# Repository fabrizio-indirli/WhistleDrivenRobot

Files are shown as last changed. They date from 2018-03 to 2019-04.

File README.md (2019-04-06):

# Whistle Driven Robot

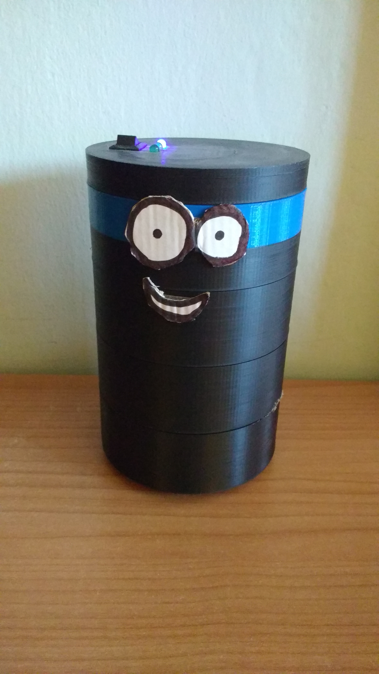
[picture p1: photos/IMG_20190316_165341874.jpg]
Robot Photo
 
This project was developed for the course _Advanced Operating
Systems_ in the academic year 2017/2018 on the Politecnico of Milan.

#### Purpose

This project consists in a robot controlled by a whistle
that can be used to play some simple games, as following a path
or making some races. It is composed by two parts:
- The robot: realized through an Arduino Nano and 3D printed;
- The transmitter: an STM32F407 Discovery that recognizes
the frequency of the sound and sends the oppotune command
to the robot using a Bluetooth module.

#### Used libraries
- STM32 OS Miosix: https://miosix.org/
- Lorenzo Binosi and Matheus Fim’s Guitar Tuner Project: 
https://github.com/LorenzoBinosi/AOSProject?files=1

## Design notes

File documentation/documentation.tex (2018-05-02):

\documentclass{article}
\usepackage{graphicx}
\usepackage{float}
\usepackage{hyperref}
\usepackage{url}

\begin{document}
	\input{files/titlepage}
	\newpage
	
	\tableofcontents
	\setcounter{page}{0}
	\addtocontents{toc}{\protect\thispagestyle{empty}}
	\newpage
	
	\section{Introduction}
	\input{files/introduction}
	\newpage
	
	\section{Transmitter}
	\input{files/microphone}
	\newpage
	
	\section{Wireless Communication}
	\input{files/wirelesscommunication}
	\newpage
	
	\section{Receiver}
	\input{files/motors}
	\newpage
	
	\section{Bibliography}
	\input{files/bibliography}
	\newpage

\end{document}

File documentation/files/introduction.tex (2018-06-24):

The main goal of this project is to design a game where the user can remotely command a robot (the \textit{receiver}) by whistling in the microphone of a STM32 Discovery board (the \textit{transmitter}). In particular, this board continuously acquires sound samples from its microphone and calculates their frequency, and then sends to the robot a related command for choosing the direction to take. The game consists in a race with obstacles where the winner will be the one who completes the path before the others.

\subsection{Problem statement}
The game consists in a race between two or more robots, where each player controls one of the machines through whistles using the related Discovery board. The most skilled player in the control of the robot will be the one who arrives first at the end of the path, gaining the victory. Collisions with other players are allowed and warmly suggested.\\*
A specific movement of the robot will correspond to a precise frequency range of the whistle:
\begin{itemize}
	\item Forward movement
	\item Backward movement
	\item Left movement
	\item Right movement
\end{itemize}

\subsection{Summary of the work}
The code is organized in three main sections, in order to improve the maintainability and the creation process:
\begin{itemize}
	\item \textit{The Transmitter}: this part is composed of the Discovery board and a HD44780 display; it converts the perceived sounds in numerical frequencies. Then, the board computes the command associated to that frequency, shows it on the display (along with the recognized frequency) and sends it to the robot through bluetooth.
	\item \textit{The Communication}: this is the part that transfers the command from the Discovery board to the Arduino board through a Bluetooth channel, using two paired HC-05 modules.
	\item \textit{The Receiver}: this is the real robot, which executes the received commands and changes its state accordingly.
\end{itemize}

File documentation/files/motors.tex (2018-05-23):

The receiver is basically a robot driven by the commands from the Discovery board, which communicates through the Bluetooth channel. The receiver is implemented by an opportune object that takes the data, ignores the eventual dirty characters and executes the bound function.

\subsection{Main parts}
The robot is divided in three main parts:
\begin{itemize}
	\item \textbf{The serial communication}: this is the section that is in charge of receiving and sending strings, encapsulating all the code within an object and, consequently, allowing changes and extensions;
	\item \textbf{The Executer}: this is the object that, given a command stored in a string, looks for a function able to execute it and, in positive case, runs it;
	\item The controller: this is the part performed by the Arduino \textit{loop} metho; it invokes the serial communication methods, taking the commands strings and giving them to the executer.
\end{itemize}

\subsection{The serial communication}
\begin{figure}[h!]
	\centering
	\hspace*{-0.25 \textwidth}\includegraphics[width= 1.5\textwidth]
	{files/images/ArduinoConnection}
	\caption{The structure of the connection in the receiver.}
	\label{fig:connection}
\end{figure}
The \textit{SerialCommunication} class is a generic structure that acquires the characters from a source and converts them in strings. Consequently, this class provides few important methods to improve and to organize this process, used independently by the source nature:
\begin{itemize}
	\item \textit{updateBuffer}: this method is used to take the available characters from the receiver buffer and put them in a temporary opportune storage object (\textit{StringHandler}). If there are no characters or a line is fully read, this method simply does nothing.
	\item \textit{isAllTheLineRead}: this method returns true if a line is fully read, else it returns false.
	\item \textit{readLine}: this returns in a string all the read characters, independently if a line is fully received, and empties the buffer in \textit{StringHandler}.
	\item \textit{print}: this method prints the passed string on the connection channel, adding automatically the end line character.
\end{itemize}

\subsubsection{\textit{StringHandler}}
All the received characters are temporarily stored in an apposite data structure, called \textit{StringHandler}. This class offers some methods to manipulate these characters, allowing to know if a string is fully received and, eventually, withdraw it. It's not necessary that the string is fully received to transform all the received characters in a string. After the withdraw method invocation, the object resets itself.

\subsubsection{\textit{SerialCommunication} extensions}
In the Figure \ref{fig:connection}, in particular in the parent class, two methods are indicated as virtual, since their implementation depends by the connection type used. Consequently, the \textit{SerialCommunication} class was extended by \textit{BTSerialCommunication} and by \textit{USBSerialCommunication}, which implement these two methods, according to their specification and using proper attributes to perform these actions.\\
In the communication, the class \textit{USBSerialCommunication} and the \textit{print} method of \textit{BTSerialCommunication} are implemented but never used. They were added for debug features and for future expansion, made easier by this organization.

\subsubsection{Optimization}
Since this control requires a lot of milliseconds to perform its analysis, in the receiver it is implementer a more optimized structure to avoid this problem, in case of the need of more \textit{Real Time} performances. This structure forbids the parameters use in the connection channel, aiming to execute the command as soon as possible, reducing the buffer queue and gaining smaller latencies.\\*
This structure replaces the entire connection described with a simple object that return characters, instead of strings, taken directly by the serial channel. These characters represent the received commands without parameters and they are used by an opportune method of the \textit{Executer} object to seek and execute the opportune command. Since the architecture doesn't allow parameters, all the invoked functions received an empty string as parameter.\\*
This structure should be used when the commands stream by the Discovery is very high, consequently, the sound is very various. The optimization, on other words, empties the receiver buffer faster than the other structure.

\subsection{The Executer}
The \textit{Executer} interprets the received commands by the connection. A command is a string that has, as first character, a proper name and, subsequently, some parameters for that specific command. Its name is used to get, with a constant time through an Hash map, the method to invoke for executing that specific command. This class exposes only a method, the one invoked passing the string as parameter and that seeks and executes the opportune function.\\*
This structure allows to extends the robot with future modules, without changing this object but just adding the new function pointers to the map.\\*

\subsubsection{The used Hash map}
The quoted Hash map is not a class from the library but a proper class implemented in this code. It is not a perfect Hash function since it uses the module operation to compute the indexes but this choice was made to avoid useless computational time wastes. It is however possible change it since it is fully encapsulated in a module.\\

\subsubsection{The used commands}
This robot uses the following commands:
\begin{itemize}
	\item \textit{f}: to go forward;
	\item \textit{b}: to go back;
	\item \textit{l}: to go to the left;
	\item \textit{r}: to go to the right;
	\item \textit{s}: to stop.
\end{itemize}
The command analyzer is easily extensible and further commands can be implemented, also with parameters.
\newpage

\subsection{The circuit}
\begin{figure}[h!]
	\centering
	\hspace*{-0.15 \textwidth}\includegraphics[width= 1.3\textwidth]
	{files/images/ReceiverScheme}
	\caption{The motors circuit scheme of the robot.}
\end{figure}
For this robot, is necessary that both the motors rotate in two different directions, consequently, two basic \textit{H bridges} have been implemented to achieve this purpose. To avoid the use of inverters, it is necessary to use two pins for each motor direction, hence eight Arduino pins are used to handle the movements.\\
In other two pins, the Bluethooth module HC05 text and read pins are connected, despite it isn't shown in the circuit scheme. Also the LEDs and the eventual buzzer aren't shown.

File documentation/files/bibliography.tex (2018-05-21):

\begin{enumerate}
	\item Miosix: \href{https://miosix.org/}{https://miosix.org/};
	\item Miosix guides: \href{https://miosix.org/wiki/index.php}{https://miosix.org/wiki/index.php};
	\item Miosix and Discovery examples: \href{http://home.deib.polimi.it/fornacia/doku.php}{http://home.deib.polimi.it/fornacia/doku.php};
	\item Arduino documentation: \href{https://www.arduino.cc/reference/en/}{https://www.arduino.cc/reference/en/}.
	\item Lorenzo Binosi and Matheus Fim's Guitar Tuner Project: \\
	\href{https://github.com/LorenzoBinosi/AOSProject?files=1}{https://github.com/LorenzoBinosi/AOSProject?files=1}
	\item Tilen Majerle's tutorial \textit{STM32F4 FFT Example} on \textit{stm32f4-discovery.net}: \\
	\href{https://stm32f4-discovery.net/2014/10/stm32f4-fft-example/}{https://stm32f4-discovery.net/2014/10/stm32f4-fft-example/}
	\item \textit{Spectrum analyzer with FFT - example of application on STM32F4DISCOVERY} article on \textit{stm32.eu}:
	\href{https://stm32.eu/2014/01/09/analizator-widma-z-fft-przyklad-aplikacji-na-stm32f4discovery/}{https://stm32.eu/2014/01/09/analizator-widma-z-fft-przyklad-aplikacji-na-stm32f4discovery/}
	\item AT Command mode tutorial: \href{http://www.martyncurrey.com/arduino-with-hc-05-bluetooth-module-at-mode/}{http://www.martyncurrey.com/arduino-with-hc-05-bluetooth-module-at-mode/};
\end{enumerate}

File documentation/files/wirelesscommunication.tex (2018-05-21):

To convey the commands from the transmitter to the receiver, a wireless connection is needed, in this case
implemented through two HC-05 modules. These boards are, in technical terms, Bluetooth SPP (Serial Port Protocol) modules, used to abstract the wireless connection implementation.\\

\begin{figure}[H]
	\hspace*{0.3 \textwidth}\includegraphics[width= 0.4\textwidth]
	{files/images/hc05_view}
	\caption{View of the HC-05 surfaces.}
\end{figure}

\subsection{Command and Data Transfer modes}
This module has two modes of operation:
\begin{itemize}
	\item \textit{Command Mode} (or \textit{AT Mode}): used for configuring the module (through AT commands);
	\item \textit{Data Mode}: used for transmitting and receiving data to/from another Bluetooth module.
\end{itemize}

\subsection{Default settings}
The default settings for new modules are:
\begin{itemize}
	\item Device name: HC-05;
	\item Password: 1234;
	\item Baud rate in communication mode: 9600 characters per second (but sometimes 38400 characters per second);
	\item Baud rate in \textit{AT Mode}: 38400 characters per second;
	\item State: there are two possible states for this module, master and slave, the second is the default behaviour.
\end{itemize}
The default device mode is the \textit{Data Mode} and it is used to broadcast data through Bluetooth.\\

\subsection{\textit{AT Mode}}
AT command mode allows to interrogate and to modify the previous settings described. Changing the module state, it is possible to configure it to automatically connect to another Bluetooth device, as it will be made in this project.\\
To use the Command mode, an USB to TTL adapter or an opportunely configured Arduino board is needed. The HC05 should be connected to one of these devices according to the following scheme:\\

\begin{tabular}{|c|c|c|}
	\hline 
	\textbf{HC-05 pin} & \textbf{For \textit{USB to TTL}} & \textbf{For \textit{Arduino}} \\ 
	\hline 
	(1) +5V & Vcc & Vcc \\ 
	\hline 
	(2) GND & GND & GND \\ 
	\hline 
	(3) Tx & Rx & Rx \\ 
	\hline 
	(4) Rx & Tx & Tx \\ 
	\hline 
\end{tabular}

\subsubsection{Enter in \textit{AT Mode} through EN pin}
\begin{figure}[H]
	\hspace*{0.3 \textwidth}\includegraphics[width= 0.4\textwidth]
	{files/images/hc05_en_pin}
	\caption{HC-05 module with EN pin and button switch.}
\end{figure}
To activate \textit{AT Mode} on these HC-05 modules, the pin 34 has to be high on power up. For this purpose there are two different approaches: \begin{itemize}
\item if there is a button on the module, press it: this will automatically connect the pin 34 to the high power source
\item if not, manually connect pin 34 to a 5V voltage source through a jumper wire.
\end{itemize}
To enter this mode, the pin 34 must be connected to at least 4V when powering on the module. Once the module has booted, the voltage on pin 34 can become high impedance.\\
To verify if the module is in \textit{AT Mode}, the LED on the HC05 should blink with halved frequency.

\subsection{Setup the communication}
Once the HC-05 is in \textit{AT Mode}, the module can be configured through the \textit{Arduino Serial Module}. The configuration will require that both \textit{NL} and \textit{CR} as end line are enabled and the communication will be kept at 38400 characters per second.\\
It is necessary to set the two modules, one for the master role and one for the slave one, since the two modules should connect to each other automatically, without the support of the boards. The master will seek a Bluetooth module (the slave) whose address is the given one, and will establish the connection.

\subsubsection{Slave configuration}
The slave mode will be used on the Arduino:
\begin{enumerate}
	\item Boot the HC05 in \textit{AT Mode} and connect it to the Arduino;
	\item To verify if the connection is right, it is possible to type \textit{AT}, which should return \textit{OK};
	\item Typing \textit{AT+UART?}, the module will answer with the actual baud rate, which should be 9600 characters per second, compatible with the Arduino serial port;
	\item Typing \textit{AT+ROLE?}, the module should answer a message like \textit{+ROLE=0}, which means that the Bluetooth device is in slave mode;
	\item Typing \textit{AT+ADDR?}, the module should answer with its address, like 18:e4:34cldd, and it is necessary to use this to configure the master module.
\end{enumerate}

\begin{figure}[H]
	\hspace*{0.1 \textwidth}\includegraphics[width= 0.8\textwidth]
	{files/images/hc05_slave2}
	\caption{Slave configuration of the HC-05 module trough serial monitor.}
\end{figure}

\subsubsection{Master configuration}
The master module will be used on the Discovery board. The configuration process is similar to the previous module so here only the relevant commands will be explained.\\
\begin{enumerate}
	\item Boot the HC05 in \textit{AT Mode} and connect it to the Arduino;
	\item The STM32F407 uses \textit{9600} baud rate to communicate on USART2, so it is necessary to change the hc-05 baud rate, through the command \textit{AT+UART=9600,0,0};
	\item Typing \textit{“AT+ROLE=1”}, the serial device will set the Bluetooth module as a master device;
	\item Typing \textit{AT+CMODE=0} the serial device will set the connection mode as \textit{fixed address} and, using the \textit{AT+BIND=XX,XXXX,XX} command, putting there the slave address, the master will be set to search this module and connect there (in the address specification it is required using commas, instead of colons).
\end{enumerate}

\begin{figure}[H]
	\hspace*{0.1 \textwidth}\includegraphics[width= 0.8\textwidth]
	{files/images/hc05_master}
	\caption{Master configuration of the HC-05 module trough serial monitor.}
\end{figure}
 \newpage
 
 \subsection{The communication to the HC05 modules}
 
\subsubsection{The transmitter}
The code on the Discovery uses the USART2 channel to communicate with the connected HC-05 module.\\
So, it is necessary to link the HC-05 \textit{Rx} pin to Discovery PA2 pin (USART2 \textit{TX}) and HC-05 \textit{Tx} pin to PA3 (USART2 \textit{RX})\\
In this project, the Discovery only send strings to Arduino, so the code will only write on the PA2 pin but the implementation regards also the contrary stream for future expansions. To send a string, it is just require to use the \textit{printf} function implemented in the Miosix kernel.\\

\subsubsection{The receiver}
The project uses the pin 12 (\textit{TX}) and the pin 11 (\textit{RX}) to communicate with the HC-05 module. To read a string from the HC-05 on Arduino is enough to use the \textit{read()} function of the SoftwareSerial class.\\

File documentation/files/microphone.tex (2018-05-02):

The transmitter is the part that recognizes sounds (through a microphone) and produces commands for the robot. The STM32D407VG-Discovery board is equipped with a MP45DT02 MEMS microphone and a CS43L22 DAC for audio acquisition and processing. In this project, these devices are used to detect the sounds' frequency, which will determine the commands to give to the robot.

\subsection{The MP45DT02 microphone}
The MP45DT02-M is a compact, low-power, omnidirectional, digital MEMS (Micro Electro-Mechanical Systems) microphone.
\begin{figure}[H]
	\hspace*{0.15 \textwidth}\includegraphics[width= 0.7\textwidth]
	{files/images/board_view}
	\caption{View of the upper surface of the board, with the microphone highlighted in the circle.}
\end{figure}

In the microphone bottom surface, there are six pins:
\begin{enumerate}
	\item \textbf{GND}: Connected to the GND of the board.
	\item \textbf{LR} - Channel selection: used since the microphone is designed to allow stereo audio capture. If it is connected to GND, the MP45DT02 is placed in \textit{left} channel mode: a sample is latched to the data output pin (PDM, Pulse-Density Modulation) on a falling edge of the clock, while on the rising clock edge, the output is set to high impedance. If the LR pin is connected to Vdd then the device operates in \textit{right} channel mode and the MP45DT02 latches it's sample to PDM on a clock rising edge, setting the pin to high impedance on the falling edge of the clock.
	\item \textbf{GND}: Connected to the GND of the board.
	\item \textbf{CLK} - Synchronization input clock: this pin is connected to the PB10 port of the board. The clock signal determines the sampling frequency.
	\item \textbf{DOUT} - PDM Data Output. Connected to the PC03 pin of the board's GPIO.
	\item \textbf{VDD}: Power supply.
\end{enumerate}

\begin{figure}[H]
	\hspace*{0.3 \textwidth}\includegraphics[width= 0.4\textwidth]
	{files/images/mic_bottom_pins}
	\caption{Pins on the bottom of the microphone.}
\end{figure}

\subsection{Overview on sound acquisition and processing}
The sound is acquired by the microphone, and the communication is performed through I2C.\\
The microphone acquires data in PDM format: each sample is a single bit, so the acquisition is a stream of bits; an high amplitude is represented with an high density of \textit{1} bits in the bitstream. \\
The sampling frequency of the ADC is 44000 Hz. \\
In order to process the data, it has to be converted in PCM (Pulse-Code Modulation) format: this is done by doing \textit{CIC filtering} (Cascaded Integrator-Comb), with a decimation factor of sixteen (each 16-bits sequence of 1-bit PDM samples is converted in one 16-bit PCM sample).\\
Then, an FFT (Fast Fourier Transform) analysis is performed on 4096 samples at a time to extract the fundamental frequency and the amplitude of the sound.

\subsubsection{Microphone initialization}
The initialization of the sound acquisition system comprehends several steps:
\begin{enumerate}
	\item SPI, DMA and General Purpose ports B and C are enabled through RCC
	\item GPIO ports are configured in \textit{Alternate} mode
	\item SPI is set to work in I2S mode
	\item Interrupt handling for DMA is configured
	
\end{enumerate}

\subsubsection{Sound acquisition and processing}
Each time a new block of samples is read, the \textit{freq\_recognition} library:
\begin{enumerate}
	\item Reads blocks of sixteen bits from SPI and transfers them in RAM through DMA;
	\item Converts 16 PDM samples in one 16-bit PCM sample via \textit{CIC filtering} with a decimation factor of sixteen;
	\item Perform FFT through the \textit{arm\_cfft\_radix4\_f32} module;
	\item Calculate amplitude of each frequency with the \textit{arm\_cmplx\_mag\_f32} module;
	\item Calculate the the fundamental frequency (and its amplitude) in the vector;
	\item Store the values of the fundamental frequency and its amplitude in dedicated variables, then ivoke the \textit{callback function} to react to the detected frequency.
\end{enumerate}
In this project, the \textit{callback function} is in charge of producing commands to the engines when the frequency of the last acquired sample is in some specified ranges. These commands are sent to an appropiate object, named \textit{ReceiverState}, which sends the commands to the Arduino board. This object avoids to repeatedly send the same command, sending only the first of an all equal string series.

\subsection{The \textit{freq\_recognition} library}
This library defines a simple interface for recording audio with the embedded microphone on the STM32F4 Discovery board and for performing an FFT analysis to calculate the strongest frequency (and its amplitude) of each sample.

\subsubsection{The Microphone.cpp driver}
Sound acquisition from the embedded microphone is performed by the \textit{Microphone.cpp} driver. \\
This driver was originally developed by Riccardo Binetti, Guido Gerosa and Alessandro Mariani, but it has been improved by Lorenzo Binosi and Matheus Fim in their \textit{Digital Guitar Tuner} project. \\
For this project, some little changes were made to the driver, such as reducing the decimation factor to improve sampling frequency.

\subsubsection{Interface of the library}
The \textit{freq\_recognition} library provides the following functions:
\begin{itemize}
	\item \textbf{\textit{void startAcquisition(function\textless void ()\textgreater cback, float32\_t* freqVar, float32\_t* amplitudeVar)}}, whose parameters are:
	\begin{itemize}
		\item \textit{cback}: a pointer to the callback function that will be executed automatically each time a new sample has been acquired and processed;
		\item \textit{freqVar}: pointer to the float32\_t where the detected frequency of each sample will be stored;
		\item \textit{amplitudeVar}: pointer to the float32\_t where the detected amplitude of each sample will be stored.
	\end{itemize}
\item \textbf{\textit{void stopAcquisition()}}: stops the acquisition of new samples.
\end{itemize}

\subsubsection{How it works}
The \textit{freq\_recognition} library wraps the microphone driver and adds the FFT analysis features. \\
When the \textit{startAcquisition()} method is called, the library retrieves the Microphone object (which is a singleton) and configures it to execute the \textit{FFTandCallback} function each time a new chunk of PDM samples is produced (each chunk has FFT\_SIZE samples). Then, the \textit{FFTandCallback} function:
\begin{enumerate}
	\item Initializes the ARM Complex-FFT module;
	\item Calculates the FFT, producing a vector (called \textit{input[]}) of complex numbers;
	\item Calculates the magnitude of each number in the \textit{input[]} vector and stores the values in the \textit{output[]} vector;
	\item Calls the \textit{maxFreq()} function to calculate the strongest frequency: this is done by finding the position of the greatest value in the \textit{output[]} vector, which is then multiplied for the frequency resolution, which is SAMPLING\_FREQ / FFT\_SIZE;
	\item Calls the callback function specified as parameter of the \textit{startAcquisition()}.
\end{enumerate}
\begin{figure}[H]
	\centering
	\hspace*{-0.15 \textwidth}\includegraphics[width= 1.3\textwidth]
	{files/images/freqAcquisitionUML.png}
	\caption{UML schema of the interaction between the modules in frequency recognition.}
\end{figure}

\subsubsection{Usage of the library}
The usage of the library is performed according to these steps:
\begin{enumerate}
	\item Add the \textit{freq\_recognition.cpp} and \textit{freq\_recognition.h} files in the folder of the other source files of the project, and add the \textit{freq\_recognition.cpp} entry in the \textit{SRC} line of the makefile;
	\item Add the \textit{arm\_bitereversal.c}, \textit{arm\_cfft\_radix4\_f32.c}, \textit{arm\_cfft\_radix4\_init\_f32.c} and \textit{arm\_cmplx\_mag\_f32.c} libraries to the project (these libraries are required by \textit{freq\_recognition.cpp});
	\item Add the \textit{\#include "freq\_recognition.h"} line at the start of the source file that will use the library;
	\item Declare 2 float32\_t variables to store the frequency and the amplitude of the last acquired sample;
	\item Define a void callback function without parameters;
	\item Start the acquisition by calling the \textit{startAcquisition(\&callback, \&freq, \&amplitude)} method, passing to it the addresses of the callback function and of the 2 variables. This method is non-blocking (operations are performed in other threads).
\end{enumerate}
Each time a new block of 16-bit PDM samples has been acquired, the driver will perform an FFT analysis on it and will write the frequency and the amplitude of the sample in the chosen variables, then the callback function will be called automatically. This process will be iterated continuously until the \textit{stopAcquisition()} function is called.
\newpage

\subsection{Displaying the recognized frequency}
The transmitter is equipped with a standard HD44780 LCD with two rows and sixteen columns, that is used to print the currently recognized frequency and the associated command (if any).

\subsubsection{Connections}
\begin{tabular}{|c|c|}
	\hline 
	\textbf{LCD pin} & \textbf{Connected to} \\ 
	\hline 
	(1) Vss & GND \\ 
	\hline 
	(2) Vdd & 5V \\ 
	\hline 
	(3) V0 & center tap of a potentiometer between 5V and GND \\ 
	\hline 
	(4) RS & PE7 pin of the Discovery board \\ 
	\hline 
	(5) RW & GND \\ 
	\hline 
	(6) E & PE8 pin of the Discovery board \\ 
	\hline 
	(7) D0 & 5V \\ 
	\hline 
	(8) D1 & 5V \\ 
	\hline 
	(9) D2 & 5V \\ 
	\hline 
	(10) D3 & 5V \\ 
	\hline 
	(11) D4 & PE11 pin of the Discovery board \\ 
	\hline 
	(12) D5 & PE12 pin of the Discovery board \\ 
	\hline 
	(13) D6 & PE13 pin of the Discovery board \\ 
	\hline 
	(14) D7 & PE14 pin of the Discovery board \\ 
	\hline 
	(15) A & 3.3V \\ 
	\hline 
	(16) K & GND \\ 
	\hline 
\end{tabular} 

\subsubsection{Driver and usage}
The driver of the display for Miosix is available in the OS itself: to use it, the \textit{utils/lcd44780.h} library has been included in the main program. \\
	In the software, the display is represented as an instance of the \textit{Lcd44780} class, whose constructor needs to know the pins of the board on which the RS, E, D4, D5, D6, D7 display pins are connected. Through this object, these methods are available:
 \begin{itemize}
 	\item \textit{clear()} to wipe the content of the screen;
 	\item \textit{go(column, row)} moves the cursor to the specified position;
 	\item \textit{printf()} prints to the display, using the standard C formatting rules.
 \end{itemize}

To reduce the risk of printing errors and the required number of updates, the \textit{Lcd44780} instance is encapsulated in an class, named \textit{Display}, in the homonym package. This class exposes only two methods: the first is to set the frequency and the others to set the commands. When one of these are invoked, it will update the display if and only if the passed value is not yet shown.

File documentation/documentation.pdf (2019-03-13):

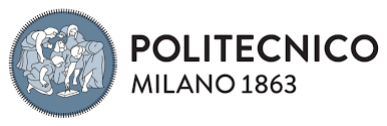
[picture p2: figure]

# Embedded Systems Advanced Operating Systems Project Academic year 2017/2018

# Whistle Robot

# Version 1.0 June 8th 2018

# Borgo Daniele 894110 Fusca Yuri 898602 Indirli Fabrizio 899892

# Advisor : Federico Terraneo Professor: William Fornaciari

## Contents

1 Introduction | 1
2 Transmitter | 2
3 Wireless Communication | 8
4 Receiver | 13
5 Bibliography | 17

## 1 Introduction

The main goal of this project is to design a game where the user can remotely command a robot (the receiver ) by whistling in the microphone of a STM32 Discovery board (the transmitter ). In particular, this board continuously acquires sound samples from its microphone and calculates their frequency, and then sends to the robot a related command for choosing the direction to take. The game consists in a race with obstacles where the winner will be the one who completes the path before the others.

### 1.1 Problem statement

The game consists in a race between two or more robots, where each player controls one of the machines through whistles using the related Discovery board. The most skilled player in the control of the robot will be the one who arrives first at the end of the path, gaining the victory. Collisions with other players are allowed and warmly suggested.
A specific movement of the robot will correspond to a precise frequency range of the whistle:
- Forward movement
- Backward movement
- Left movement
- Right movement

### 1.2 Summary of the work

The code is organized in three main sections, in order to improve the maintainability and the creation process:

- The Transmitter : this part is composed of the Discovery board and a HD44780 display; it converts the perceived sounds in numerical frequencies. Then, the board computes the command associated to that frequency, shows it on the display (along with the recognized frequency) and sends it to the robot through bluetooth.
- The Communication: this is the part that transfers the command from the Discovery board to the Arduino board through a Bluetooth channel, using two paired HC-05 modules.
- The Receiver : this is the real robot, which executes the received commands and changes its state accordingly.

1

## 2 Transmitter

The transmitter is the part that recognizes sounds (through a microphone) and produces commands for the robot. The STM32D407VG-Discovery board is equipped with a MP45DT02 MEMS microphone and a CS43L22 DAC for audio acquisition and processing. In this project, these devices are used to detect the sounds’ frequency, which will determine the commands to give to the robot.

### 2.1 The MP45DT02 microphone

The MP45DT02-M is a compact, low-power, omnidirectional, digital MEMS (Micro Electro-Mechanical Systems) microphone.

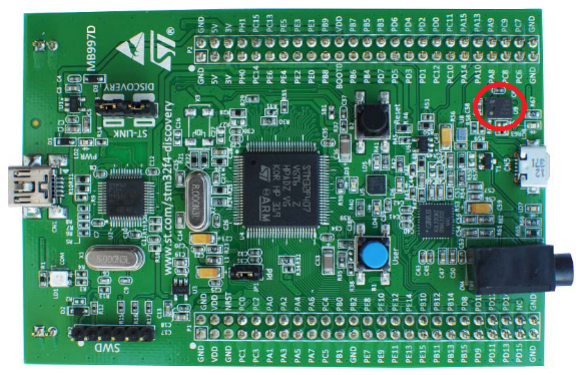
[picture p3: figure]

Figure 1: View of the upper surface of the board, with the microphone highlighted in the circle.

In the microphone bottom surface, there are six pins:

1. GND: Connected to the GND of the board.
2. LR - Channel selection: used since the microphone is designed to allow stereo audio capture. If it is connected to GND, the MP45DT02 is placed in left channel mode: a sample is latched to the data output pin (PDM, Pulse-Density Modulation) on a falling edge of the clock, while on the rising clock edge, the output is set to high impedance. If the LR pin is connected to Vdd then the device operates in right channel mode and the MP45DT02 latches it’s sample to PDM on a clock rising edge, setting the pin to high impedance on the falling edge of the clock.
3. GND: Connected to the GND of the board.
4. CLK - Synchronization input clock: this pin is connected to the PB10 port of the board. The clock signal determines the sampling frequency.

2

5. DOUT - PDM Data Output. Connected to the PC03 pin of the board’s GPIO.
6. VDD: Power supply.

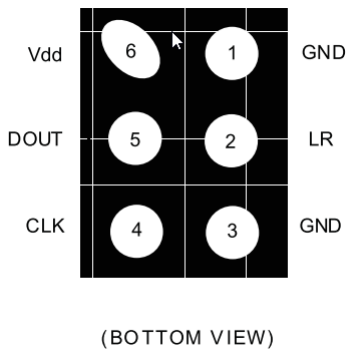
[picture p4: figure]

Figure 2: Pins on the bottom of the microphone.

### 2.2 Overview on sound acquisition and processing

The sound is acquired by the microphone, and the communication is performed through I2C.
The microphone acquires data in PDM format: each sample is a single bit, so the acquisition is a stream of bits; an high amplitude is represented with an high density of 1 bits in the bitstream.
The sampling frequency of the ADC is 44000 Hz.
In order to process the data, it has to be converted in PCM (Pulse-Code Modulation) format: this is done by doing CIC filtering (Cascaded Integrator-Comb), with a decimation factor of sixteen (each 16-bits sequence of 1-bit PDM samples is converted in one 16-bit PCM sample).
Then, an FFT (Fast Fourier Transform) analysis is performed on 4096 samples at a time to extract the fundamental frequency and the amplitude of the sound.

### 2.2.1 Microphone initialization

The initialization of the sound acquisition system comprehends several steps:

1. SPI, DMA and General Purpose ports B and C are enabled through RCC
2. GPIO ports are configured in Alternate mode
3. SPI is set to work in I2S mode
4. Interrupt handling for DMA is configured

3

### 2.2.2 Sound acquisition and processing

Each time a new block of samples is read, the freq recognition library:

1. Reads blocks of sixteen bits from SPI and transfers them in RAM through DMA;
2. Converts 16 PDM samples in one 16-bit PCM sample via CIC filtering with a decimation factor of sixteen;
3. Perform FFT through the arm cfft radix4 f32 module;
4. Calculate amplitude of each frequency with the arm cmplx mag f32 module;
5. Calculate the the fundamental frequency (and its amplitude) in the vector;
6. Store the values of the fundamental frequency and its amplitude in dedicated variables, then ivoke the callback function to react to the detected frequency.

In this project, the callback function is in charge of producing commands to the engines when the frequency of the last acquired sample is in some specified ranges. These commands are sent to an appropiate object, named Receiver-State, which sends the commands to the Arduino board. This object avoids to repeatedly send the same command, sending only the first of an all equal string series.

### 2.3 The freq recognition library

This library defines a simple interface for recording audio with the embedded microphone on the STM32F4 Discovery board and for performing an FFT analysis to calculate the strongest frequency (and its amplitude) of each sample.

### 2.3.1 The Microphone.cpp driver

Sound acquisition from the embedded microphone is performed by the Microphone.cpp driver.
This driver was originally developed by Riccardo Binetti, Guido Gerosa and Alessandro Mariani, but it has been improved by Lorenzo Binosi and Matheus Fim in their Digital Guitar Tuner project.
For this project, some little changes were made to the driver, such as reducing the decimation factor to improve sampling frequency.

### 2.3.2 Interface of the library

The freq recognition library provides the following functions:

- void startAcquisition(function<void ()>cback, float32 t* freq-Var, float32 t* amplitudeVar), whose parameters are:

4

– cback: a pointer to the callback function that will be executed automatically each time a new sample has been acquired and processed; – freqVar : pointer to the float32 t where the detected frequency of each sample will be stored;
– amplitudeVar : pointer to the float32 t where the detected amplitude of each sample will be stored.
- void stopAcquisition(): stops the acquisition of new samples.

### 2.3.3 How it works

The freq recognition library wraps the microphone driver and adds the FFT analysis features.
When the startAcquisition() method is called, the library retrieves the Microphone object (which is a singleton) and configures it to execute the FFTand-Callback function each time a new chunk of PDM samples is produced (each chunk has FFT SIZE samples). Then, the FFTandCallback function:
1. Initializes the ARM Complex-FFT module;
2. Calculates the FFT, producing a vector (called input[]) of complex numbers;
3. Calculates the magnitude of each number in the input[] vector and stores the values in the output[] vector;
4. Calls the maxFreq() function to calculate the strongest frequency: this is done by finding the position of the greatest value in the output[] vector, which is then multiplied for the frequency resolution, which is SAM-PLING FREQ / FFT SIZE;
5. Calls the callback function specified as parameter of the startAcquisition().

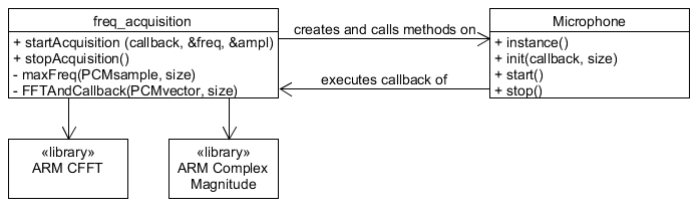
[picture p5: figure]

Figure 3: UML schema of the interaction between the modules in frequency recognition.

5

### 2.3.4 Usage of the library

The usage of the library is performed according to these steps:

1. Add the freq recognition.cpp and freq recognition.h files in the folder of the other source files of the project, and add the freq recognition.cpp entry in the SRC line of the makefile;
2. Add the arm bitereversal.c, arm cfft radix4 f32.c, arm cfft radix4 init f32.c and arm cmplx mag f32.c libraries to the project (these libraries are required by freq recognition.cpp);
3. Add the #include ”freq recognition.h” line at the start of the source file that will use the library;
4. Declare 2 float32 t variables to store the frequency and the amplitude of the last acquired sample;
5. Define a void callback function without parameters;
6. Start the acquisition by calling the startAcquisition(&callback, &freq, &amplitude) method, passing to it the addresses of the callback function and of the 2 variables. This method is non-blocking (operations are performed in other threads).

Each time a new block of 16-bit PDM samples has been acquired, the driver will perform an FFT analysis on it and will write the frequency and the amplitude of the sample in the chosen variables, then the callback function will be called automatically. This process will be iterated continuously until the stopAcquisition() function is called.

6

### 2.4 Displaying the recognized frequency

The transmitter is equipped with a standard HD44780 LCD with two rows and sixteen columns, that is used to print the currently recognized frequency and the associated command (if any).

### 2.4.1 Connections

LCD pin | Connected to
(1) Vss | GND
(2) Vdd | 5V
(3) V0 | center tap of a potentiometer between 5V and GND
(4) RS | PE7 pin of the Discovery board
(5) RW | GND
(6) E | PE8 pin of the Discovery board
(7) D0 | 5V
(8) D1 | 5V
(9) D2 | 5V
(10) D3 | 5V
(11) D4 | PE11 pin of the Discovery board
(12) D5 | PE12 pin of the Discovery board
(13) D6 | PE13 pin of the Discovery board
(14) D7 | PE14 pin of the Discovery board
(15) A | 3.3V
(16) K | GND

### 2.4.2 Driver and usage

The driver of the display for Miosix is available in the OS itself: to use it, the utils/lcd44780.h library has been included in the main program.
In the software, the display is represented as an instance of the Lcd44780 class, whose constructor needs to know the pins of the board on which the RS, E, D4, D5, D6, D7 display pins are connected. Through this object, these methods are available:
- clear() to wipe the content of the screen;
- go(column, row) moves the cursor to the specified position;
- printf() prints to the display, using the standard C formatting rules.

To reduce the risk of printing errors and the required number of updates, the Lcd44780 instance is encapsulated in an class, named Display, in the homonym package. This class exposes only two methods: the first is to set the frequency and the others to set the commands. When one of these are invoked, it will update the display if and only if the passed value is not yet shown.

7

## 3 Wireless Communication

To convey the commands from the transmitter to the receiver, a wireless connection is needed, in this case implemented through two HC-05 modules. These boards are, in technical terms, Bluetooth SPP (Serial Port Protocol) modules, used to abstract the wireless connection implementation.

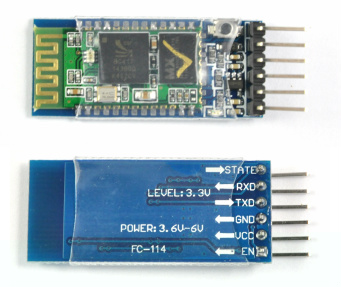
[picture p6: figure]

Figure 4: View of the HC-05 surfaces.

### 3.1 Command and Data Transfer modes

This module has two modes of operation:

- Command Mode (or AT Mode): used for configuring the module (through AT commands);
- Data Mode: used for transmitting and receiving data to/from another Bluetooth module.

### 3.2 Default settings

The default settings for new modules are:

- Device name: HC-05;
- Password: 1234;
- Baud rate in communication mode: 9600 characters per second (but sometimes 38400 characters per second);
- Baud rate in AT Mode: 38400 characters per second;
- State: there are two possible states for this module, master and slave, the second is the default behaviour.

The default device mode is the Data Mode and it is used to broadcast data through Bluetooth.

8

### 3.3 AT Mode

AT command mode allows to interrogate and to modify the previous settings described. Changing the module state, it is possible to configure it to automatically connect to another Bluetooth device, as it will be made in this project. To use the Command mode, an USB to TTL adapter or an opportunely configured Arduino board is needed. The HC05 should be connected to one of these devices according to the following scheme:

HC-05 pin | For USB to TTL | For Arduino
(1) +5V | Vcc | Vcc
(2) GND | GND | GND
(3) Tx | Rx | Rx
(4) Rx | Tx | Tx

### 3.3.1 Enter in AT Mode through EN pin

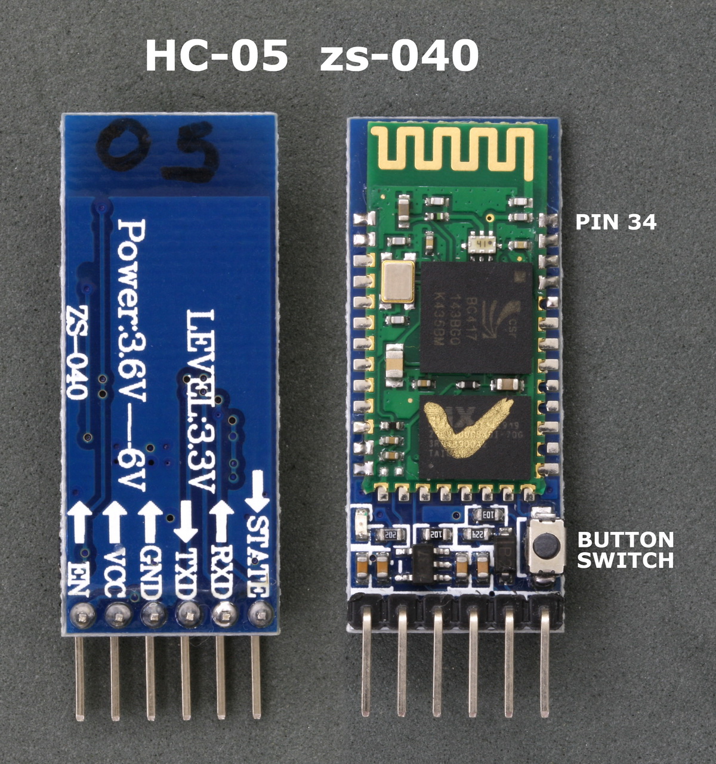
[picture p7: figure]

Figure 5: HC-05 module with EN pin and button switch.

To activate AT Mode on these HC-05 modules, the pin 34 has to be high on power up. For this purpose there are two different approaches:

- if there is a button on the module, press it: this will automatically connect the pin 34 to the high power source
- if not, manually connect pin 34 to a 5V voltage source through a jumper wire.

To enter this mode, the pin 34 must be connected to at least 4V when powering on the module. Once the module has booted, the voltage on pin 34 can become high impedance.
To verify if the module is in AT Mode, the LED on the HC05 should blink with halved frequency.

9

### 3.4 Setup the communication

Once the HC-05 is in AT Mode, the module can be configured through the Arduino Serial Module. The configuration will require that both NL and CR as end line are enabled and the communication will be kept at 38400 characters per second.
It is necessary to set the two modules, one for the master role and one for the slave one, since the two modules should connect to each other automatically, without the support of the boards. The master will seek a Bluetooth module (the slave) whose address is the given one, and will establish the connection.

### 3.4.1 Slave configuration

The slave mode will be used on the Arduino:

1. Boot the HC05 in AT Mode and connect it to the Arduino;
2. To verify if the connection is right, it is possible to type AT, which should return OK;
3. Typing AT+UART?, the module will answer with the actual baud rate, which should be 9600 characters per second, compatible with the Arduino serial port;
4. Typing AT+ROLE?, the module should answer a message like +ROLE=0, which means that the Bluetooth device is in slave mode;
5. Typing AT+ADDR?, the module should answer with its address, like 18:e4:34cldd, and it is necessary to use this to configure the master module.

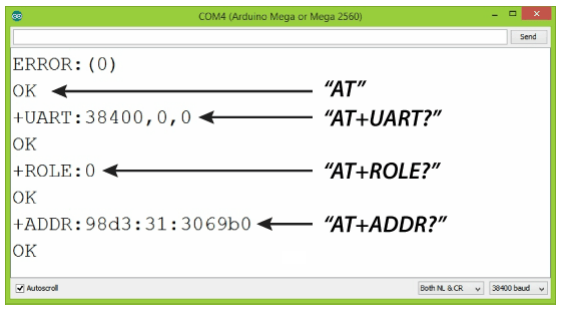
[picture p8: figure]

Figure 6: Slave configuration of the HC-05 module trough serial monitor.

10

### 3.4.2 Master configuration

The master module will be used on the Discovery board. The configuration process is similar to the previous module so here only the relevant commands will be explained.

1. Boot the HC05 in AT Mode and connect it to the Arduino;
2. The STM32F407 uses 9600 baud rate to communicate on USART2, so it is necessary to change the hc-05 baud rate, through the command AT+UART=9600,0,0 ;
3. Typing AT+ROLE=1, the serial device will set the Bluetooth module as a master device;
4. Typing AT+CMODE=0 the serial device will set the connection mode as fixed address and, using the AT+BIND=XX,XXXX,XX command, putting there the slave address, the master will be set to search this module and connect there (in the address specification it is required using commas, instead of colons).

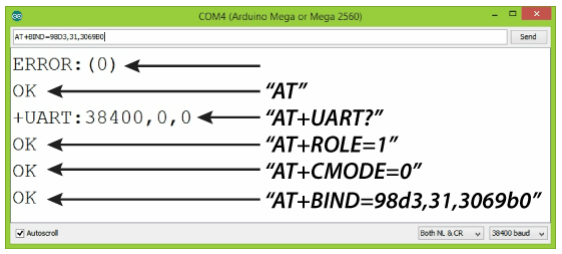
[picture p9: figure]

Figure 7: Master configuration of the HC-05 module trough serial monitor.

11

### 3.5 The communication to the HC05 modules

### 3.5.1 The transmitter

The code on the Discovery uses the USART2 channel to communicate with the connected HC-05 module.
So, it is necessary to link the HC-05 Rx pin to Discovery PA2 pin (USART2 TX ) and HC-05 Tx pin to PA3 (USART2 RX )
In this project, the Discovery only send strings to Arduino, so the code will only write on the PA2 pin but the implementation regards also the contrary stream for future expansions. To send a string, it is just require to use the printf function implemented in the Miosix kernel.

### 3.5.2 The receiver

The project uses the pin 12 (TX ) and the pin 11 (RX ) to communicate with the HC-05 module. To read a string from the HC-05 on Arduino is enough to use the read() function of the SoftwareSerial class.

12

## 4 Receiver

The receiver is basically a robot driven by the commands from the Discovery board, which communicates through the Bluetooth channel. The receiver is implemented by an opportune object that takes the data, ignores the eventual dirty characters and executes the bound function.

### 4.1 Main parts

The robot is divided in three main parts:

- The serial communication: this is the section that is in charge of receiving and sending strings, encapsulating all the code within an object and, consequently, allowing changes and extensions;
- The Executer: this is the object that, given a command stored in a string, looks for a function able to execute it and, in positive case, runs it;
- The controller: this is the part performed by the Arduino loop metho; it invokes the serial communication methods, taking the commands strings and giving them to the executer.

### 4.2 The serial communication

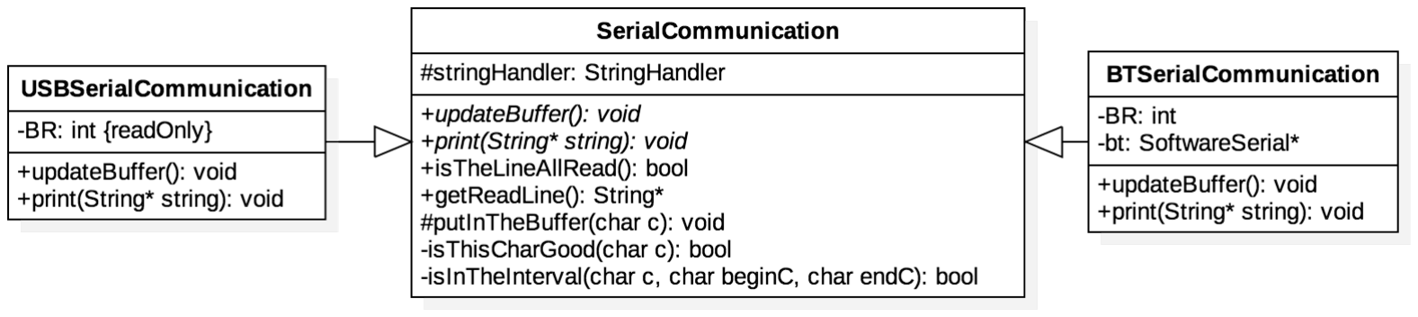
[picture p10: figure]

Figure 8: The structure of the connection in the receiver.

The SerialCommunication class is a generic structure that acquires the characters from a source and converts them in strings. Consequently, this class provides few important methods to improve and to organize this process, used independently by the source nature:

- updateBuffer : this method is used to take the available characters from the receiver buffer and put them in a temporary opportune storage object (StringHandler ). If there are no characters or a line is fully read, this method simply does nothing.

13

- isAllTheLineRead: this method returns true if a line is fully read, else it returns false.
- readLine: this returns in a string all the read characters, independently if a line is fully received, and empties the buffer in StringHandler.
- print: this method prints the passed string on the connection channel, adding automatically the end line character.

### 4.2.1 StringHandler

All the received characters are temporarily stored in an apposite data structure, called StringHandler. This class offers some methods to manipulate these characters, allowing to know if a string is fully received and, eventually, withdraw it. It’s not necessary that the string is fully received to transform all the received characters in a string. After the withdraw method invocation, the object resets itself.

### 4.2.2 SerialCommunication extensions

In the Figure 8, in particular in the parent class, two methods are indicated as virtual, since their implementation depends by the connection type used. Consequently, the SerialCommunication class was extended by BTSerialCommunication and by USBSerialCommunication, which implement these two methods, according to their specification and using proper attributes to perform these actions.
In the communication, the class USBSerialCommunication and the print method of BTSerialCommunication are implemented but never used. They were added for debug features and for future expansion, made easier by this organization.

### 4.2.3 Optimization

Since this control requires a lot of milliseconds to perform its analysis, in the receiver it is implementer a more optimized structure to avoid this problem, in case of the need of more Real Time performances. This structure forbids the parameters use in the connection channel, aiming to execute the command as soon as possible, reducing the buffer queue and gaining smaller latencies. This structure replaces the entire connection described with a simple object that return characters, instead of strings, taken directly by the serial channel. These characters represent the received commands without parameters and they are used by an opportune method of the Executer object to seek and execute the opportune command. Since the architecture doesn’t allow parameters, all the invoked functions received an empty string as parameter.
This structure should be used when the commands stream by the Discovery is very high, consequently, the sound is very various. The optimization, on other words, empties the receiver buffer faster than the other structure.

14

### 4.3 The Executer

The Executer interprets the received commands by the connection. A command is a string that has, as first character, a proper name and, subsequently, some parameters for that specific command. Its name is used to get, with a constant time through an Hash map, the method to invoke for executing that specific command. This class exposes only a method, the one invoked passing the string as parameter and that seeks and executes the opportune function.
This structure allows to extends the robot with future modules, without changing this object but just adding the new function pointers to the map.

### 4.3.1 The used Hash map

The quoted Hash map is not a class from the library but a proper class implemented in this code. It is not a perfect Hash function since it uses the module operation to compute the indexes but this choice was made to avoid useless computational time wastes. It is however possible change it since it is fully encapsulated in a module.

### 4.3.2 The used commands

This robot uses the following commands:

- f : to go forward;
- b: to go back;
- l: to go to the left;
- r : to go to the right;
- s: to stop.

The command analyzer is easily extensible and further commands can be implemented, also with parameters.

15

### 4.4 The circuit

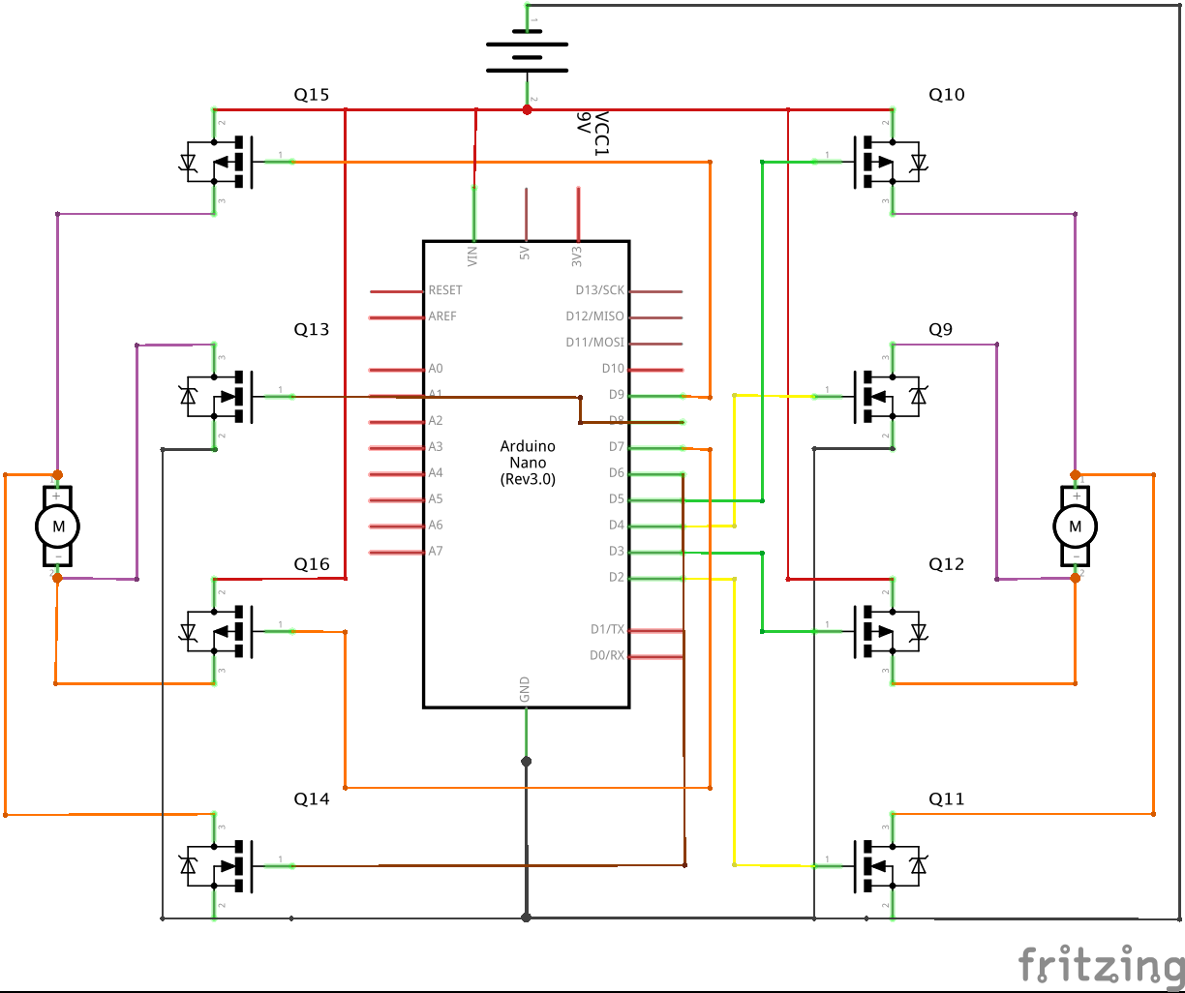
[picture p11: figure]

Figure 9: The motors circuit scheme of the robot.

For this robot, is necessary that both the motors rotate in two different directions, consequently, two basic H bridges have been implemented to achieve this purpose. To avoid the use of inverters, it is necessary to use two pins for each motor direction, hence eight Arduino pins are used to handle the movements.
In other two pins, the Bluethooth module HC05 text and read pins are connected, despite it isn’t shown in the circuit scheme. Also the LEDs and the eventual buzzer aren’t shown.

16

## 5 Bibliography

1. Miosix: https://miosix.org/;
2. Miosix guides: https://miosix.org/wiki/index.php;
3. Miosix and Discovery examples: http://home.deib.polimi.it/fornacia/doku.php;
4. Arduino documentation: https://www.arduino.cc/reference/en/.
5. Lorenzo Binosi and Matheus Fim’s Guitar Tuner Project: https://github.com/LorenzoBinosi/AOSProject?files=1
6. Tilen Majerle’s tutorial STM32F4 FFT Example on stm32f4-discovery.net: https://stm32f4-discovery.net/2014/10/stm32f4-fft-example/
7. Spectrum analyzer with FFT - example of application on STM32F4DISCOVERY article on stm32.eu: https://stm32.eu/2014/01/09/analizator-widma-zfft-przyklad-aplikacji-na-stm32f4discovery/ (https://stm32.eu/2014/01/09/analizator-widma-z-fft-przyklad-aplikacji-na-stm32f4discovery/)
8. AT Command mode tutorial: http://www.martyncurrey.com/arduino-withhc-05-bluetooth-module-at-mode/; (http://www.martyncurrey.com/arduino-with-hc-05-bluetooth-module-at-mode/)

17

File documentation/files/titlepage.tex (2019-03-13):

\begin{titlepage}
	\begin{center}
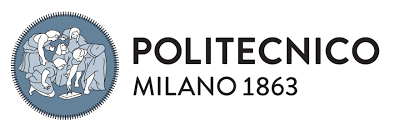
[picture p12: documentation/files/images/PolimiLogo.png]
		
		\ \\ \ \\ \ \\ \ \\ \ \\
		\huge Embedded Systems \\
		\huge Advanced Operating Systems Project
		Academic year 2017/2018
		\ \\ \ \\
		\textbf{Whistle Robot}
		\ \\ \ \\ \ \\
		\textbf{Version 1.0}\\*
		June 8th 2018
		\ \\ \ \\ \ \\
		\begin{tabular}{ l c }
			Borgo Daniele & 894110\\
			Fusca Yuri & 898602 \\
			Indirli Fabrizio & 899892 \\
		\end{tabular}
		\ \\ \ \\
		Advisor : Federico Terraneo \\
		Professor: William Fornaciari
	\end{center}
\end{titlepage}

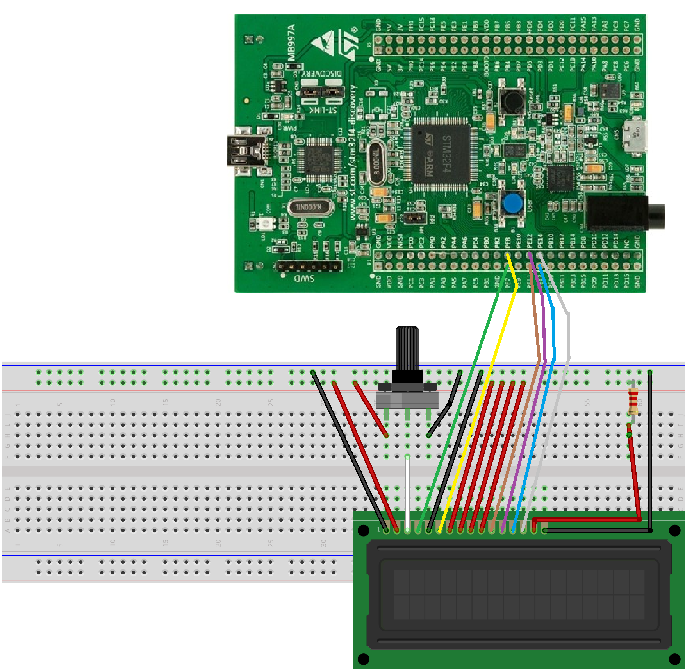
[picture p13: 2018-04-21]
documentation/files/images/display_schematic.png

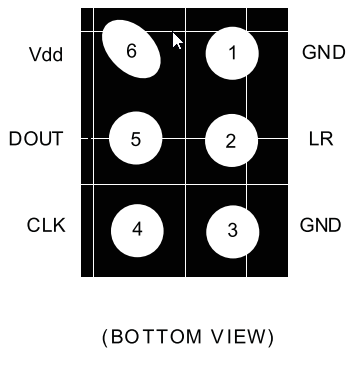
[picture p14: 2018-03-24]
documentation/files/images/mic_bottom_pins.png

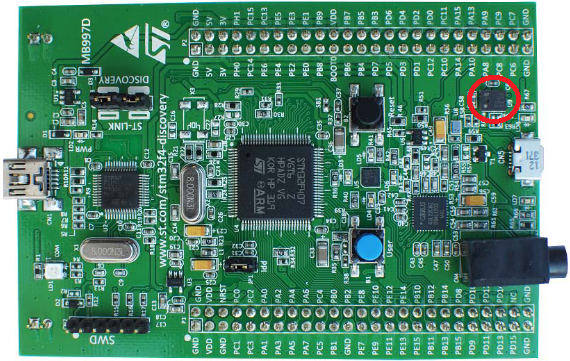
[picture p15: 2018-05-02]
documentation/files/images/board_view.png

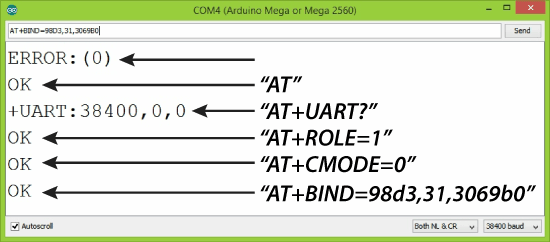
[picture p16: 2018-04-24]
documentation/files/images/hc05_master.png

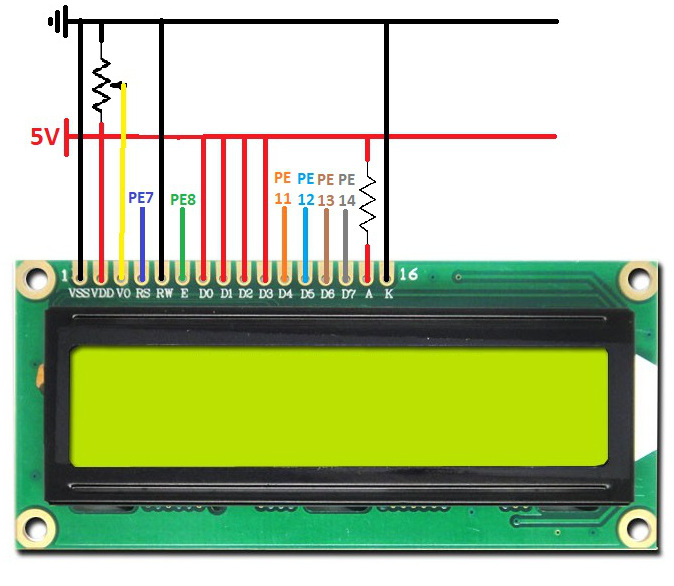
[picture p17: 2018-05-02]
documentation/files/images/display_connections.jpg

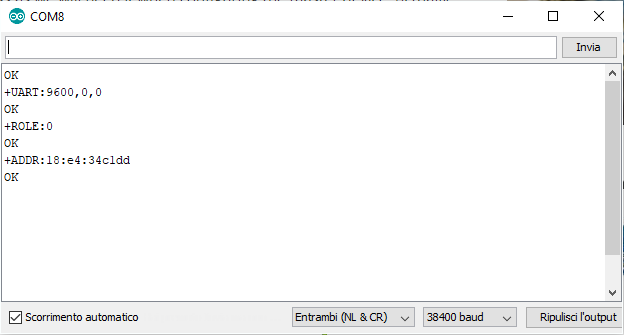
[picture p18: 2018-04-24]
documentation/files/images/hc05_slave.PNG

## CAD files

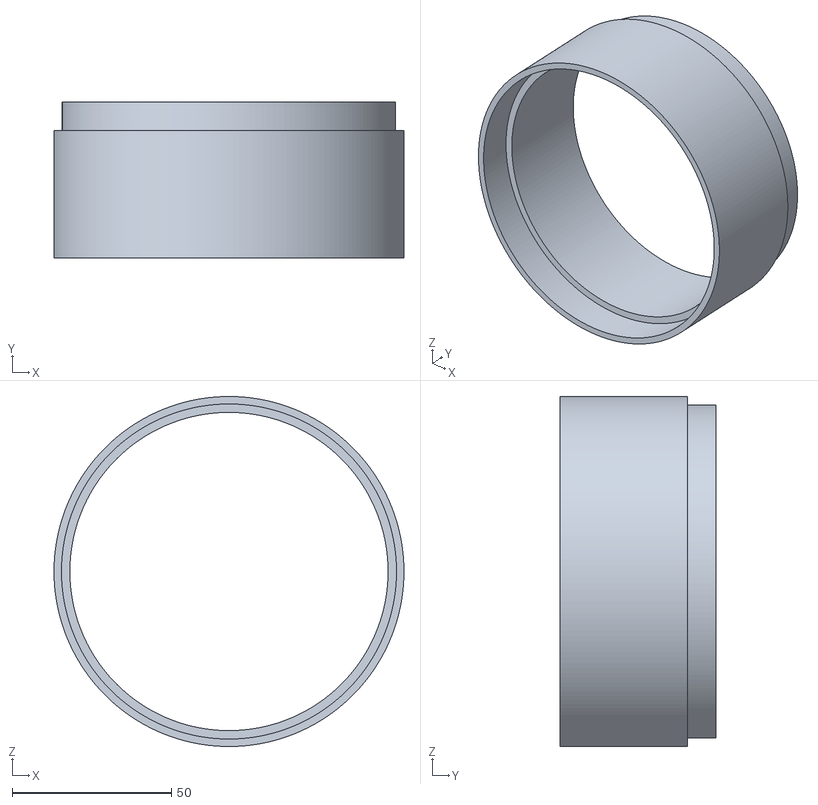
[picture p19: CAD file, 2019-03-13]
3D models/v3/black/2 Cilinder Module.stl
110.0 x 49.0 x 110.0

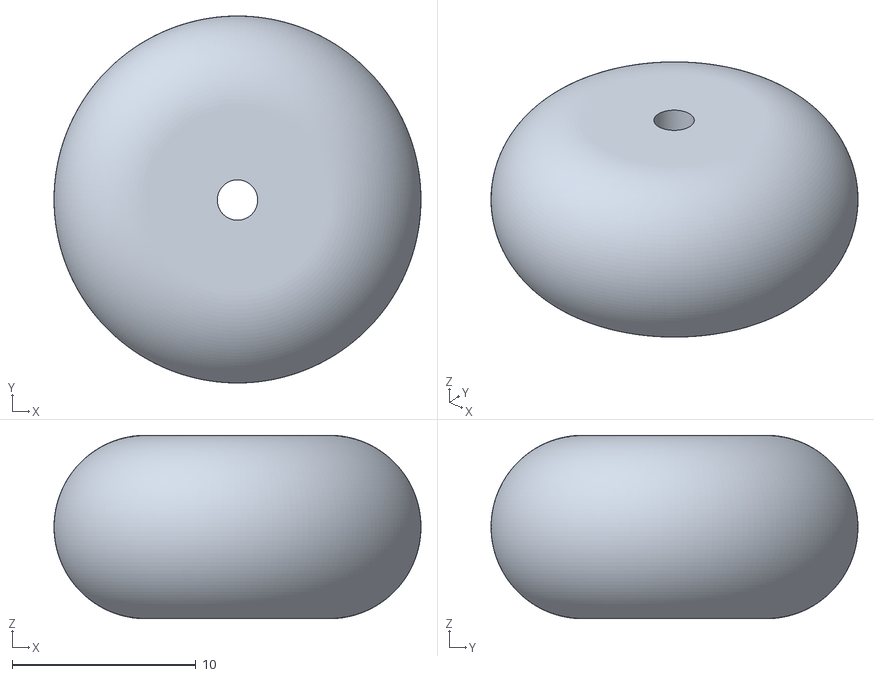
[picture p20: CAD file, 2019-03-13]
3D models/v3/light blue/2 Little Wheel.stl
20.0 x 20.0 x 10.0

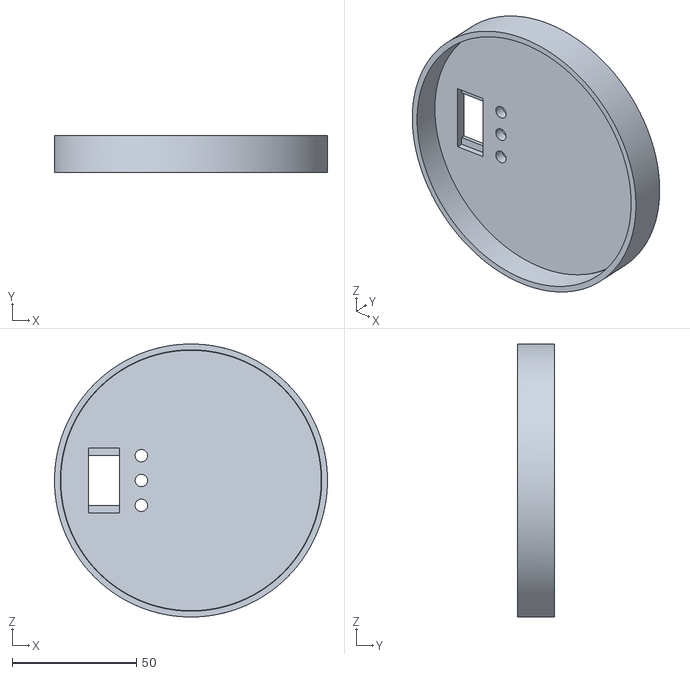
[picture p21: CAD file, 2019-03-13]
3D models/v3/black/1 Cover.stl
110.0 x 15.0 x 110.0

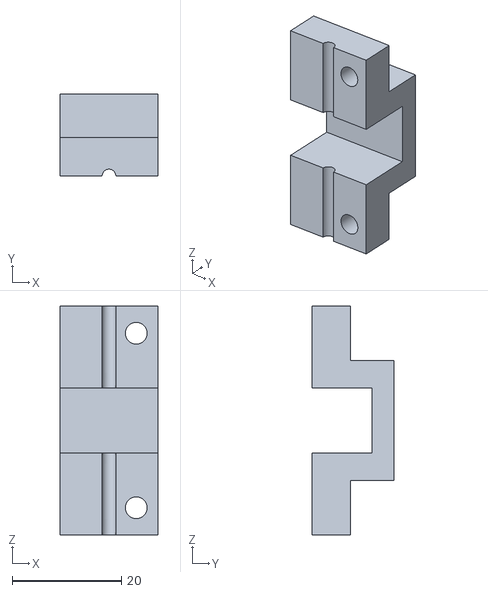
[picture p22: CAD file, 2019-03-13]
3D models/v3/light blue/2 Little Wheel Holder.stl
18.0 x 15.0 x 42.0

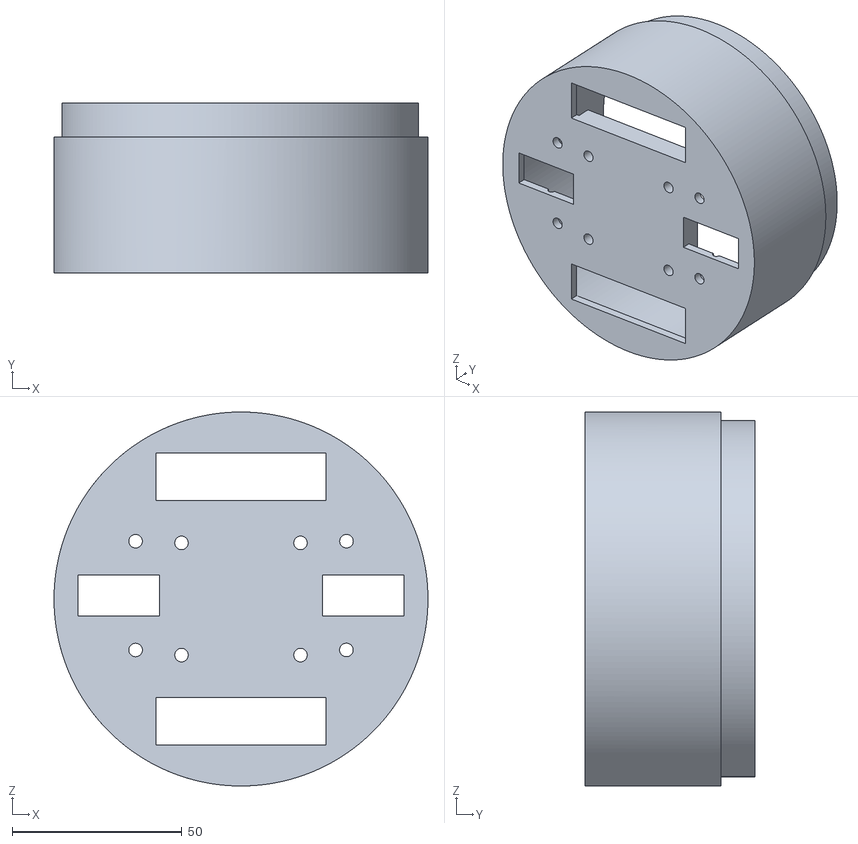
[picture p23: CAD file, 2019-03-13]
3D models/v3/black/1 Body.stl
110.0 x 50.0 x 110.0

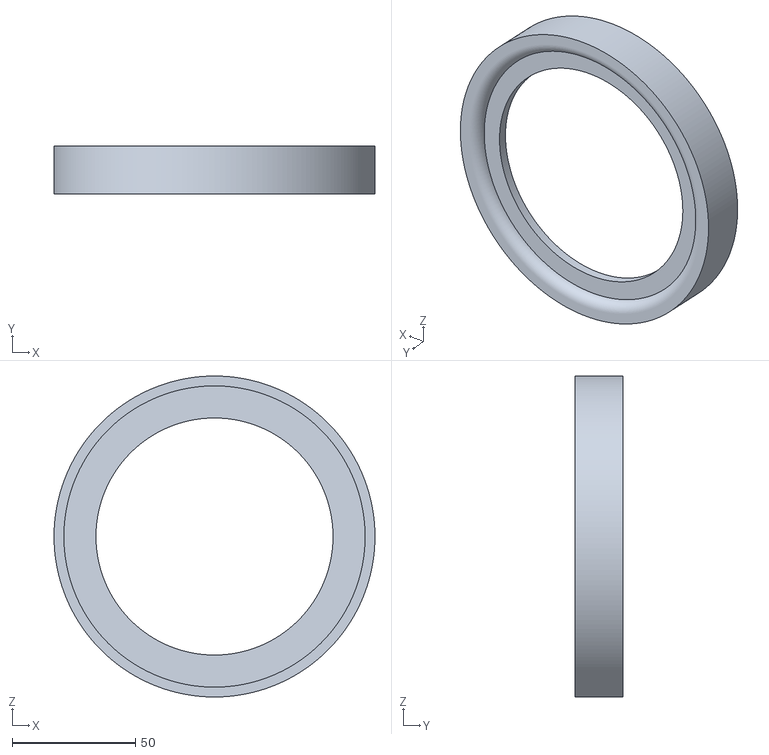
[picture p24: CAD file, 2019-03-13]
3D models/v3/light blue/1 Support.stl
130.0 x 19.5 x 130.0

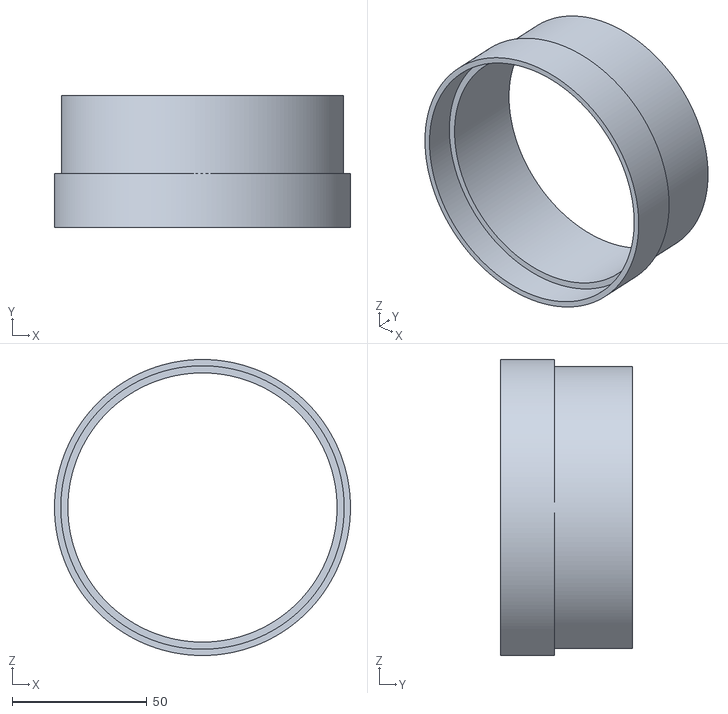
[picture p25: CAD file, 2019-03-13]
3D models/v3/black/1 Cilinder Module Mod.stl
110.0 x 49.0 x 110.0

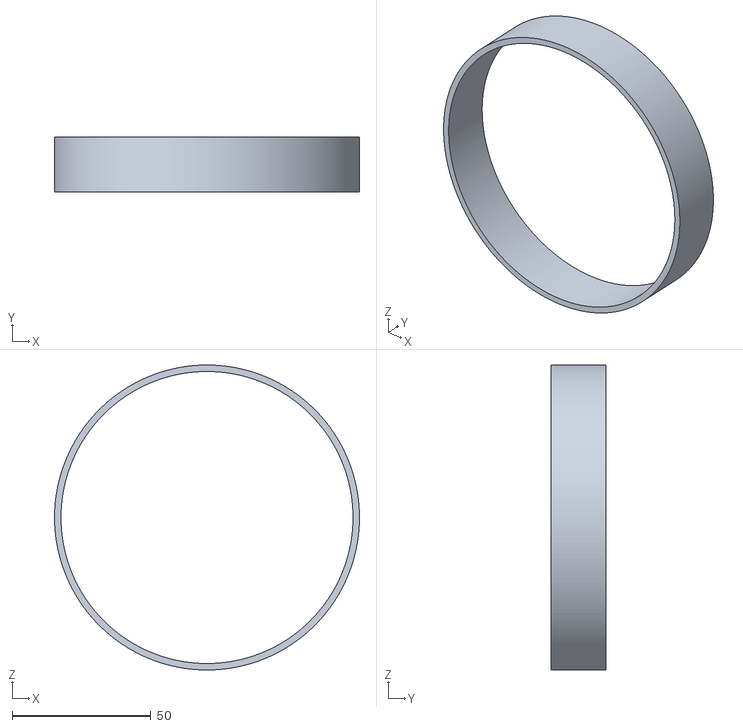
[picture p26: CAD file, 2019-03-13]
3D models/v3/light blue/1 Ring.stl
110.0 x 20.0 x 110.0

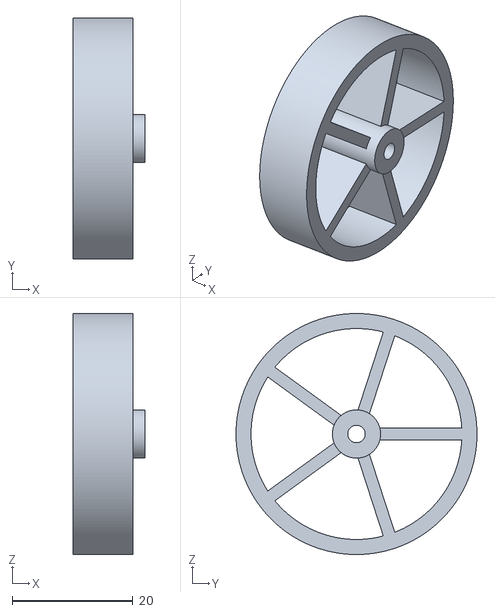
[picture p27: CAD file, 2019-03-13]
3D models/v3/light blue/2 Wheel.stl
12.0 x 40.0 x 40.0

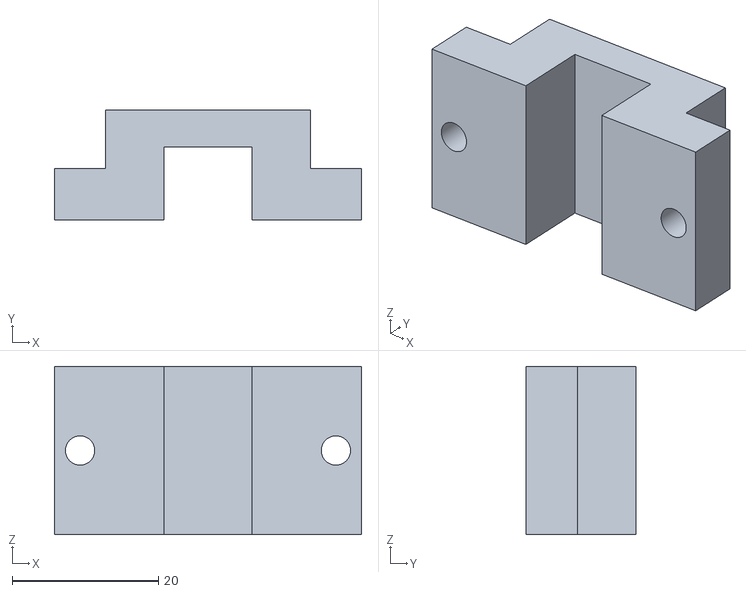
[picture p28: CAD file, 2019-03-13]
3D models/v3/light blue/2 Wheel Holder.stl
42.0 x 15.0 x 23.0

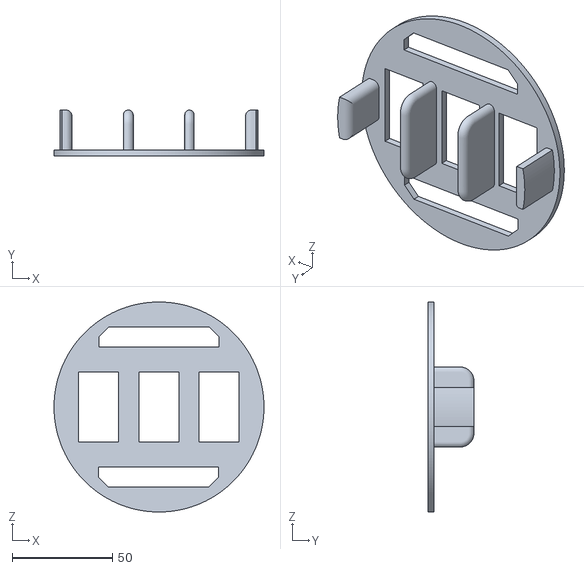
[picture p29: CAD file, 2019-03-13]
3D models/v3/light blue/1 Batteries Holder.stl
104.9 x 23.0 x 104.9

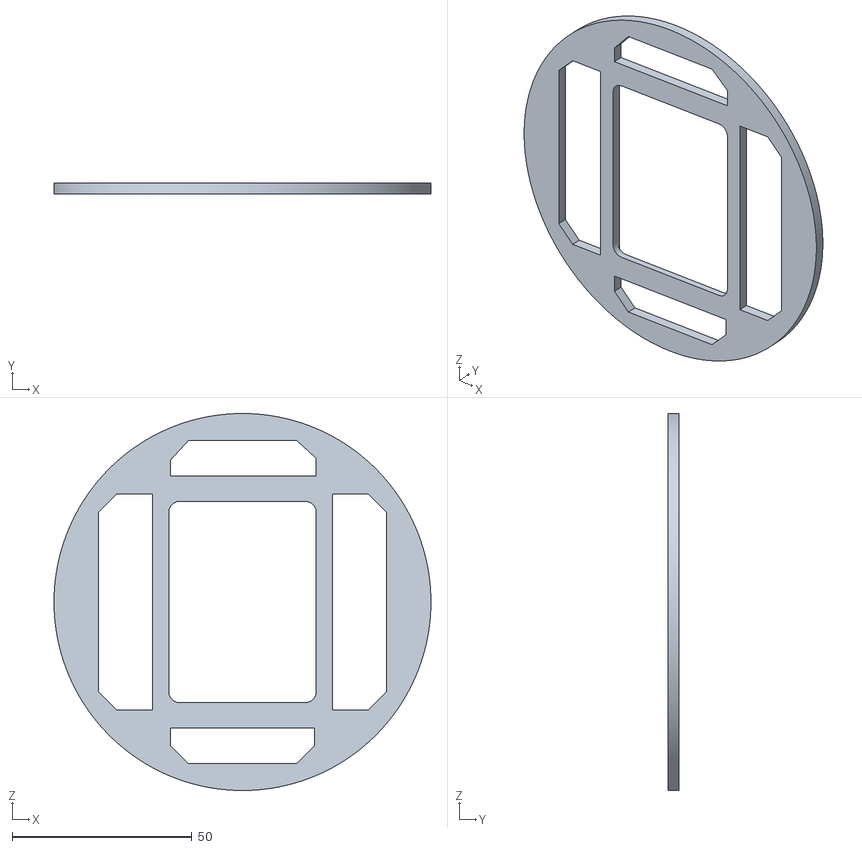
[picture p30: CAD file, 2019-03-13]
3D models/v3/light blue/1 Eletronics Holder.stl
104.9 x 3.00 x 104.9

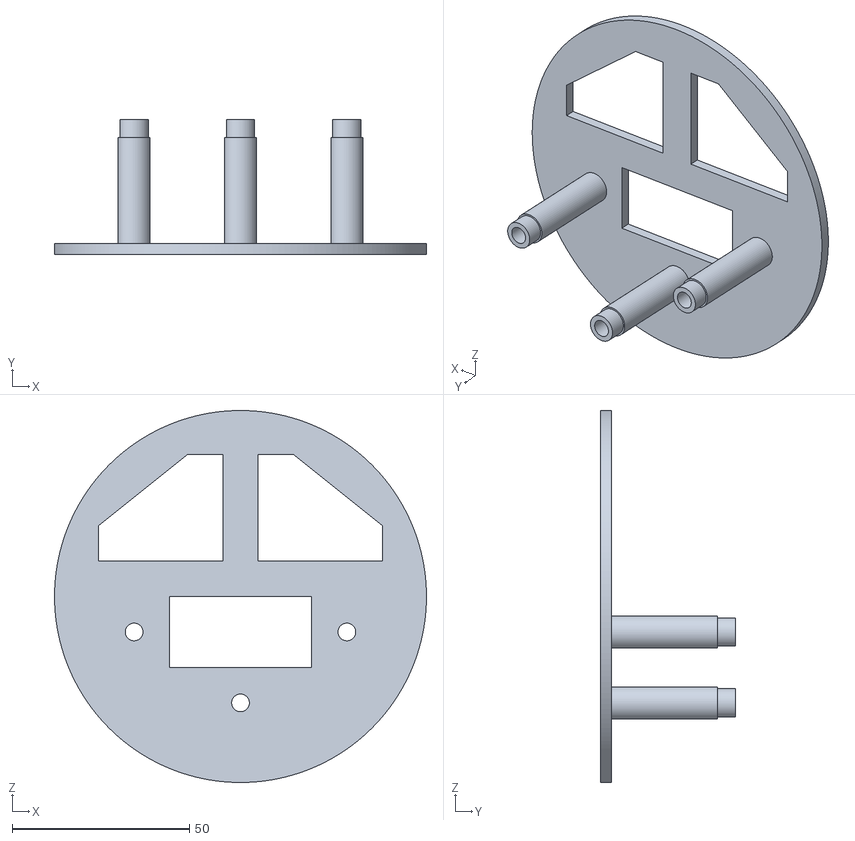
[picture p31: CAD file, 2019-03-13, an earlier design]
3D models/v2/Weights Holder.stl
104.9 x 38.0 x 104.9

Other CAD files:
3D models/v2/Body.stl
3D models/v2/3 Cilinder Module.stl

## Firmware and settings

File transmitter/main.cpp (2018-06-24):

#include <cstdio>
#include "miosix.h"
#include <string>
#include "freq_recognition/freq_recognition.h"
#include <util/lcd44780.h>
#include <stdio.h>
#include <display/display.h>
#include <ReceiverState.h>

#define SAMPLES 8192 //audio samples acquired each time
#define FFT_SIZE SAMPLES/2 //we store only the real parts of the samples

//this is the minimum amplitude of the acquired sound in order to activate the engines
#define AMPLITUDE_THRESHOLD 20000000

//if the sound's frequency is between these 2 values, the car will move forward
#define FORWARD_MIN_FREQ 500
#define FORWARD_MAX_FREQ 1000

//if the sound's frequency is between these 2 values, the car will turn left
#define TURNLEFT_MIN_FREQ 1100
#define TURNLEFT_MAX_FREQ 1800

//if the sound's frequency is between these 2 values, the car will turn right
#define TURNRIGHT_MIN_FREQ 2000
#define TURNRIGHT_MAX_FREQ 2800

//if the sound's frequency is between these 2 values, the car will move backwards
#define BACKWARD_MIN_FREQ 3000
#define BACKWARD_MAX_FREQ 4000

using namespace std;
using namespace miosix;

/**
 * This is the LED used to signal a valid command reception.
 */
typedef Gpio<GPIOD_BASE,12>  greenLed;

/**
 * This variable contains the amplitude of the last audio sample acquired.
 */
static float32_t fundamentalFreqAmplitude = 0;

/**
 * This variable stores the frequency of the last audio sample acquired.
 */
static float32_t freq=0;

/**
 * This is the display used to show the frequency and the command to execute
 */
Display display;

/**
 * This is the object that receives all the commands for the robots
 */
ReceiverState state;

/**
 * This function is invoked everytime a new audo sample has been acquired and processed.
 * when this function is called, the variables "freq" and "fundamentalFreqAmplitude" already contains
 * the frequency and the amplitude of the last acquired sample, respectively.
 */
void callback(){

    if(!(fundamentalFreqAmplitude>AMPLITUDE_THRESHOLD)){
    	display.setFrequencyTooLow();
    	display.setCommand(STOP);
    	state.setState(STOP);
    	greenLed::low();
    	return;
    }
	
	fundamentalFreqAmplitude= fundamentalFreqAmplitude * (500/((int)freq));

    if(freq < FORWARD_MAX_FREQ && freq > FORWARD_MIN_FREQ) {
            //if the frequency of the detected sound is between the FORWARD_MIN_FREQ and FORWARD_MAX_FREQ values, move forward
            greenLed::high();
			display.setCommand(FORWARD);
           	state.setState(FORWARD);
    }
    else if(freq>TURNLEFT_MIN_FREQ && freq < TURNLEFT_MAX_FREQ) {
            //if the frequency of the detected sound is between the TURNLEFT frequency values, turn left
            greenLed::high();
			display.setCommand(LEFT);
            state.setState(LEFT);
    }
    else if(freq>TURNRIGHT_MIN_FREQ && freq < TURNRIGHT_MAX_FREQ) {
            //if the frequency of the detected sound is between the TURNRIGHT frequency values, turn right
            greenLed::high();
			display.setCommand(RIGHT);
            state.setState(RIGHT);
    }
    else if(freq>BACKWARD_MIN_FREQ && freq<BACKWARD_MAX_FREQ) {
            //if the frequency of the detected sound is between the BACKWARD_MIN_FREQ and BACKWARD_MAX_FREQ values, move backwards
            greenLed::high();
            display.setCommand(BACK);
            state.setState(BACK);
    }
    else {//if the sound is not strong enough, or if the frequency is not in the accepted ranges, stop all the engines
            greenLed::low();
			display.setCommand(STOP);
			state.setState(STOP);
    }

    //print on USB serial (for debugging)
    //printf("\nFrequency: %.2f hz, Amplitude: %.2f", freq, fundamentalFreqAmplitude);

    display.setFrequency(freq);
}

int main(int argc, char *argv[]){
	//greenLed setup
	greenLed::mode(Mode::OUTPUT);
	greenLed::low();
	state.setState(STOP);

    //start audio frequency recognition
    startAcquisition(&callback, &freq, &fundamentalFreqAmplitude);

    while(true); //this in necessary because startAcquisition() works in another thread and it is non-blocking
}

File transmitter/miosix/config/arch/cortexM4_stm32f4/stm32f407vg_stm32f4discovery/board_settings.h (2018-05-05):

/***************************************************************************
 *   Copyright (C) 2012, 2013, 2014 by Terraneo Federico                   *
 *                                                                         *
 *   This program is free software; you can redistribute it and/or modify  *
 *   it under the terms of the GNU General Public License as published by  *
 *   the Free Software Foundation; either version 2 of the License, or     *
 *   (at your option) any later version.                                   *
 *                                                                         *
 *   This program is distributed in the hope that it will be useful,       *
 *   but WITHOUT ANY WARRANTY; without even the implied warranty of        *
 *   MERCHANTABILITY or FITNESS FOR A PARTICULAR PURPOSE.  See the         *
 *   GNU General Public License for more details.                          *
 *                                                                         *
 *   As a special exception, if other files instantiate templates or use   *
 *   macros or inline functions from this file, or you compile this file   *
 *   and link it with other works to produce a work based on this file,    *
 *   this file does not by itself cause the resulting work to be covered   *
 *   by the GNU General Public License. However the source code for this   *
 *   file must still be made available in accordance with the GNU General  *
 *   Public License. This exception does not invalidate any other reasons  *
 *   why a work based on this file might be covered by the GNU General     *
 *   Public License.                                                       *
 *                                                                         *
 *   You should have received a copy of the GNU General Public License     *
 *   along with this program; if not, see <http://www.gnu.org/licenses/>   *
 ***************************************************************************/

#ifndef BOARD_SETTINGS_H
#define	BOARD_SETTINGS_H

#include "util/version.h"

/**
 * \internal
 * Versioning for board_settings.h for out of git tree projects
 */
#define BOARD_SETTINGS_VERSION 100

namespace miosix {

/**
 * \addtogroup Settings
 * \{
 */

/// Size of stack for main().
/// The C standard library is stack-heavy (iprintf requires 1KB) but the
/// STM32F407VG only has 192KB of RAM so there is room for a big 4K stack.
const unsigned int MAIN_STACK_SIZE=4*1024;

/// Frequency of tick (in Hz). The frequency of the STM32F100RB timer in the
/// stm32vldiscovery board can be divided by 1000. This allows to use a 1KHz
/// tick and the minimun Thread::sleep value is 1ms
/// For the priority scheduler this is also the context switch frequency
const unsigned int TICK_FREQ=1000;

///\internal Aux timer run @ 100KHz
///Note that since the timer is only 16 bits this imposes a limit on the
///burst measurement of 655ms. If due to a pause_kernel() or
///disable_interrupts() section a thread runs for more than that time, a wrong
///burst value will be measured
const unsigned int AUX_TIMER_CLOCK=100000;
const unsigned int AUX_TIMER_MAX=0xffff; ///<\internal Aux timer is 16 bits

/// Serial port
const unsigned int defaultSerial=2;
const unsigned int defaultSerialSpeed=9600;
const bool defaultSerialFlowctrl=false;
//#define SERIAL_1_DMA //Serial 1 is not used, so not enabling DMA
//#define SERIAL_2_DMA //Serial 2 DMA conflicts with I2S driver in the examples
//#define SERIAL_3_DMA

//#define I2C_WITH_DMA

//SD card driver
static const unsigned char sdVoltage=30; //Board powered @ 3.0V
#define SD_ONE_BIT_DATABUS //Can't use 4 bit databus due to pin conflicts

/**
 * \}
 */

} //namespace miosix

#endif	/* BOARD_SETTINGS_H */

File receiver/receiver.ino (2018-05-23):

#include "src/commands/Executer.h"
/**
 * If this define is enabled, the compiler will create a code that executes
 * the received commands without expecting parameters. This choice increase
 * the performarces but forbid any parameters sending in the Bluetooth channel.
 */
#define OPTIMIZATION 1
#ifndef OPTIMIZATION
#include "src/communication/BTSerialCommunication.h"
#include "src/communication/USBSerialCommunication.h"
#else
#include "src/optimized-communication/optimized-communication.h"
#endif

#ifndef OPTIMIZATION
SerialCommunication* communication;
String* string;
#else
OptimizedCommunication optimized_communication;
#endif
Executer* executer;

void setup() {
#ifndef OPTIMIZATION
    communication = new BTSerialCommunication();
#endif
    executer = new Executer();
}

void loop() {
#ifndef OPTIMIZATION
    communication->updateBuffer();
    if(communication->isTheLineAllRead()){
  	    string = communication->getReadLine();
  	    Serial.println(*string);
  	    executer->execute(string);
    }
#else
    if(optimized_communication.doYouHaveCharacters()){
        char c = optimized_communication.read();
        if(isALowerCaseLiteralChar(c))
            executer->optimizedExecute(c);
    }
#endif
}

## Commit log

2017-11-14 Added datasheet, programming manual and windows software for the STM32F407_DISCOVERY board
2017-12-05 added link to stm repo for audio rec
    [Calcoli_motore.xlsx]
2017-12-05 Updated useful material
2017-12-06 Aggiornato useful material
2018-02-27 New experiments folder
    [Calcoli_motore.xlsx]
2018-03-08 updated main
    [EthBoardV2.cfg, anakin.cfg, bitsboard.cfg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]
2018-03-23 Updated frequency recognition code
    [EthBoardV2.cfg, anakin.cfg, bitsboard.cfg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]
2018-03-24 Delete board_view.png
    Removed unused file
2018-04-04 Bug fix on Bluetooth connection
    [receiver.ino]
2018-04-06 Bug fix on Bluetooth connection and on StringHandler
    [receiver.ino]
2018-04-06 Added the circuit scheme
    [Receiver Scheme.fzz]
2018-04-07 Added the motors controls
2018-04-08 Bug fix: added a characters filter
    [receiver.ino]
2018-04-09 Impemented frequency recognition in Microphone class, added code with 4 frequency intervals
    [EthBoardV2.cfg, anakin.cfg, bitsboard.cfg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]
2018-04-11 Added "The Microphone.cpp driver" subsection in the documentation
2018-04-11 Completed the Arduino documentation in the code
2018-04-12 Moved transmitter directory to repository's root
    [EthBoardV2.cfg, anakin.cfg, bitsboard.cfg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]
2018-04-16 Improved frequency recognition
    [EthBoardV2.cfg, anakin.cfg, bitsboard.cfg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]
2018-04-17 added low-filtering (freqs > 10k hz are discarded)
2018-04-21 little fix on arduino code (and documentation)
    [ArduinoBluetoothTest.ino]
2018-04-21 bluetooth code integrated into transmitter folder (stm32 code)
2018-04-21 aggiornato codice arduino con uno switch case che gestisce i 4 comandi inviati da discovery
2018-04-22 Updated and corrected the receiver documentation and circuit scheme
    [Receiver Scheme.fzz]
2018-04-22 Bug fix on the transmitter
    [main.cpp]
2018-04-22 switched to miosix printf for the serial communication with the hc-05 module
2018-04-22 commentato printf di debug
2018-04-23 bluetooth test (arduino) ora ignora i caratteri di disturbo e di accapo
2018-04-24 update documentation of wireless communication in latex
2018-04-24 small changes in the documentation (wireless paragraph)
2018-04-24 small changes in the documentation (wireless)
2018-04-24 Bug fix on motors controller
    [filler.cpp, filler.h, main.cpp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]
2018-04-26 Bug fix on the receiver
    [ArduinoBluetoothTest.ino, receiver.ino]
2018-04-29 Improved the display handling incapsulating it in a proper object on the Discovery and bug fix on the receiver code
    [main.cpp, receiver.ino]
2018-04-30 Bug fix on the transmitter: now the Discovery avoid to send an overwhelming stream of the same string to the receiver
    [main.cpp, receiver.ino]
2018-05-05 Updated ArduinoBluetoothTest to implement all the commands; changed STM32 baud rate to 9600
2018-05-05 DOC: small fix on wireless documentation (stm32 now uses 9600 baud rate instead of 19200)
2018-05-20 Bug fix on receiver
    [main.cpp]
2018-05-21 updated bibliography and little fixes on wireless documentation
2018-05-29 Bug fix on the receiver scheme (wire overlap)
    [Receiver Scheme.fzz]
2019-03-11 removed useless material
    [EthBoardV2.cfg, anakin.cfg, bitsboard.cfg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]
2019-03-13 Minor bug fixes, uploaded STLs and wrote the readme
    [1 Batteries Holder.stl, 1 Body.stl, 1 Cilinder Module Mod.stl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]
